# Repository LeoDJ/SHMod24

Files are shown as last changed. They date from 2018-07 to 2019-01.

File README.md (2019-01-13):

# SHMod24
(Smart Home Module NRF24)

WORK IN PROGRESS.

This PCB is a universal microcontroller board with many optionally placable components. It aims to be an universal base-board for many projects especially around home automation.

## Features
- Choice of ATMega328 (Arduino Pro Mini) or ESP8266 (ESP12-F) as the µC
- NRF24L01+ SMD with power filtering
- 6-30V input with buck converter
- Lithium battery support with charging and protection circuit
- 3.3V supply and logic
- Some MOSFET capable outputs
- RS485 Transceiver

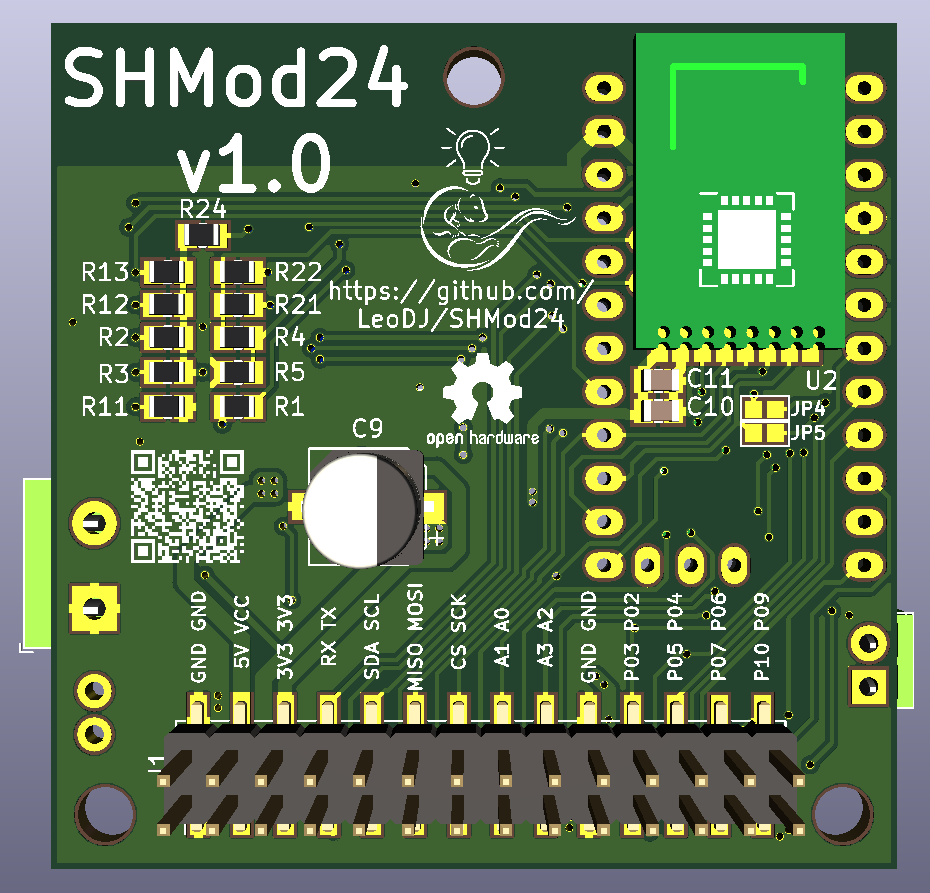
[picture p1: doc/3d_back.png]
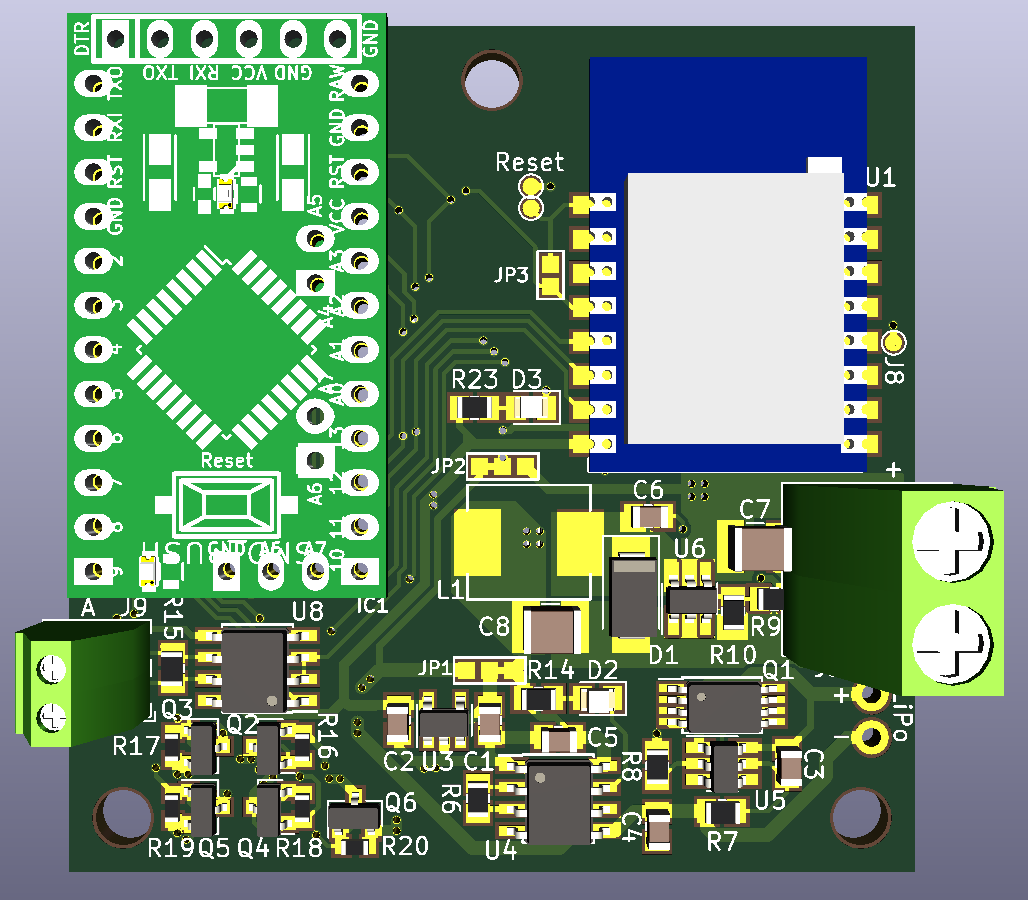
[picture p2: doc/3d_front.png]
|  |  |
| :--- | :--- |
| []() | []() |

## Pinout
The pinout of the 28 pin header is listed here:

| ESP8266 | Arduino | Function | Pin | Pin | Function  | Arduino | ESP8266 |
| :--- | :--- | :--- | :----- | :----- | :--- | :--- | :--- |
| | | GND | **1**  | **2**  | GND | | |
| | | 5V | **3**  | **4**  | VCC | | |
| | | 3.3V | **5**  | **6**  | 3.3V | | |
| RX | RX | RX | **7**  | **8**  | TX | TX | TX |
| GPIO4 | A4 | SDA | **9**  | **10** | SCL | A5 | GPIO5 |
| GPIO12 | 12 | MISO | **11** | **12** | MOSI | 11 | GPIO13 |
| GPIO15 | 8 | CS | **13** | **14** | SCK | 13 | GPIO14 |
| | A1 | | **15** | **16** | Analog in | A0 | ADC (0-3.3V) |
| | A3 | | **17** | **18** | | A2 | |
| | | GND | **19** | **20** | GND | | |
| GPIO2 | 3 | MOSFET | **21** | **22** | | 2 | GPIO0 |
| [GPIO13]<sup>* JP4</sup> | 5 | MOSFET | **23** | **24** | | 4 | |
| GPIO16 | 7 | NRF_CE | **25** | **26** | MOSFET | 6 | [GPIO12]<sup>* JP5</sup> |
| | 10 | MOSFET | **27** | **28** | MOSFET | 9 | |

*) GPIO can be connected to this pin by bridging the mentioned jumper

**ATTENTION:** When the MAX3485 is mounted the Arduino doesn't want to be programmed most of the time. So make sure to pull pin P3 to 3.3V.
## BOM
There are multiple different module groups that can be populated.

 **Information about what to watch out for for the different module groups will follow.**

 In the table is listed, which components to populate for a given module:

| Module | Reference | Part |
| :--- | :--- | :--- |
| **ESP8266** | U1 | ESP8266 12F |
| | R1, R2, R3, R11, R24 | 10k |
| ESP8266 ADC | R4 | 220k |
| | R5 | 100k |
| | | |
| **Arduino** | IC1 | Arduino Pro Mini |
| | | |
| **NRF radio** | U2 or U7 | NRF24L01+ SMD |
| | C11 | 100nF |
| | (C10) | 10µF |
| | | |
| **3.3V regulator** | U3 | AP2112K |
| | C1, C2 | 1µF |
| | | |
| **Buck regulator** | U6 | LMR14010A<br>or ACT4088 in deadbug style  |
| | R9 | LMR14010A: 56k<br>ACT4088: 47k |
| | R10 | 10k |
| | C6 | 100n |
| | C7 | LMR14010A: 2.2µF 50V<br>ACT4088: 10µF 50V |
| | C8 | 22µF |
| | L1 | LMR14010A: 22µH<br>ACT4088: 4.7µH |
| | D1 | Schottky 40V SMA |
| | (C9) | 100µF |
| | | |
| **LiPo charger** | U4 | TP4056 |
| | R6 | 2k2 |
| | C5 | 100nF |
| | R14 | 1k |
| | D2 | 0805 SMD LED (charging indicator) |
| | | |
| **LiPo protection** | U5 | DW01A |
| | Q1 | FS8205A |
| | R7 | 100 |
| | R8 | 1k |
| | C3 | 100n |
| | | |
| **I²C pullup resistors** | R12, R13 | 10k |
| | | |
| **RS485 Transceiver** | U8 | MAX3485 |

## Project installation
- Make sure to run `git clone` with `--recurse-submodules` to include the necessary libraries too.
- To use the 3D Models, set the following environment variables:
  - **ESPLIB** : `${KIPRJMOD}\lib_includes\kicad-ESP8266`
  - **MYSLOCAL** : `${KIPRJMOD}\lib_includes`
  - Note: Sometimes you need to manually replace `${KIPRJMOD}` with the absolute path to the project

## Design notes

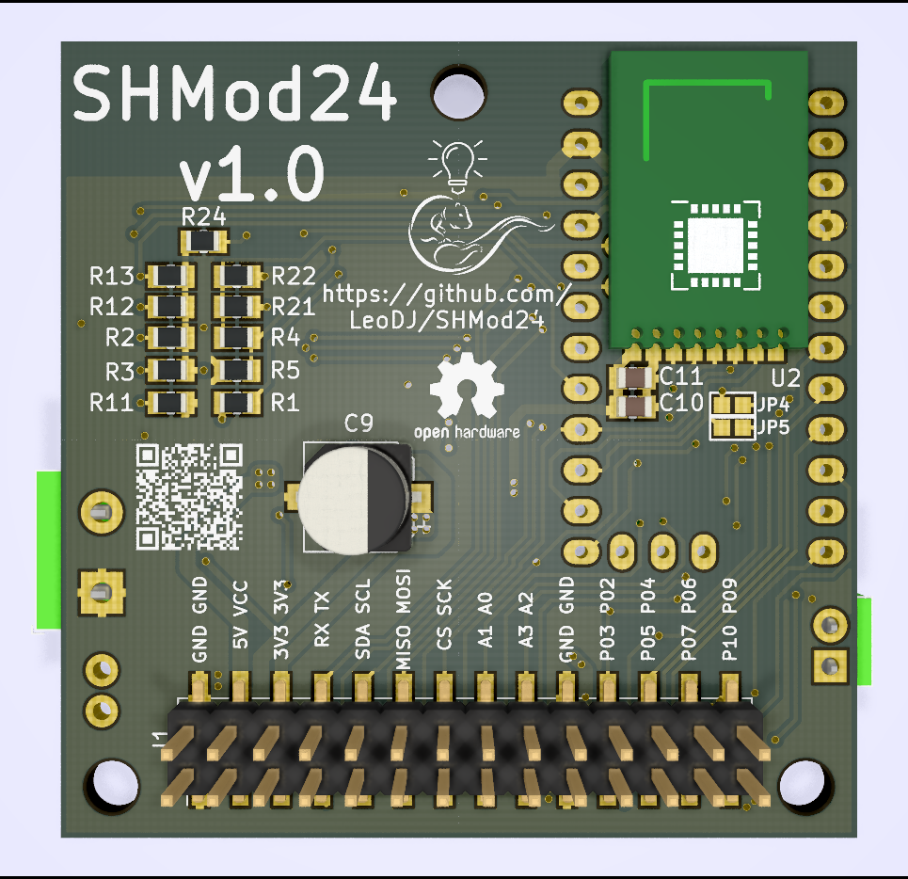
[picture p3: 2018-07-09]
doc/3d_rendered_back.png

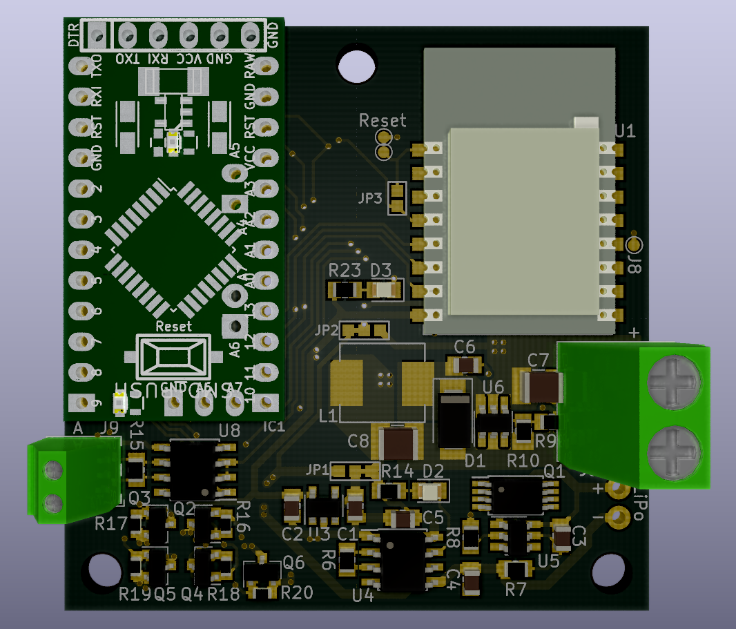
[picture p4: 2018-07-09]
doc/3d_rendered_front.png

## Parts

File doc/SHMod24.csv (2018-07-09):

Reference | Quantity | Value | Footprint | Datasheet
C1 C2 | 2 | 1µF | LeoDJ-kicad:C_0805_2012Metric
C11 C3 C5 | 3 | 100n | LeoDJ-kicad:C_0805_2012Metric
C10 C4 | 2 | 10µF | LeoDJ-kicad:C_0805_2012Metric
C6 | 1 | 100nF | LeoDJ-kicad:C_0805_2012Metric
C7 | 1 | 2.2µF 50V | Capacitor_SMD:C_1210_3225Metric
C8 | 1 | 22µF | Capacitor_SMD:C_1210_3225Metric
C9 | 1 | 100µF | Capacitor_SMD:CP_Elec_6.3x5.8
D1 | 1 | D_Schottky 40V | Diode_SMD:D_SMA
D2 D3 | 2 | LED | LED_SMD:LED_0805_2012Metric
IC1 | 1 | ArduinoProMini | mysensors_arduino:pro_mini
J1 | 1 | Conn_02x14_Odd_Even | Connector_PinHeader_2.54mm:PinHeader_2x14_P2.54mm_Vertical_SMD
J2 J3 | 2 | Conn_01x01 | Connector_Wire:SolderWirePad_1x01_Drill0.8mm
J4 | 1 | RESET | TestPoint:TestPoint_Pad_D1.0mm
J5 | 1 | 12V | TerminalBlock_Phoenix:TerminalBlock_Phoenix_MKDS-1,5-2_1x02_P5.00mm_Horizontal
J6 J8 | 2 | GND | TestPoint:TestPoint_Pad_D1.0mm
J9 | 1 | Screw_Terminal_01x02 | LeoDJ-kicad:TerminalBlock_Phoenix_MPT-0,5-2-2.54_1x02_P2.54mm_Horizontal_fixed
JP1 | 1 | Source Select | LeoDJ-kicad:SOLDER-JUMPER_2-WAY
JP2 | 1 | VoltSense | LeoDJ-kicad:SOLDER-JUMPER_2-WAY
JP3 | 1 | Jumper_DeepSleep | LeoDJ-kicad:SOLDER-JUMPER_1-WAY
JP4 JP5 | 2 | ESP_MOSFET | LeoDJ-kicad:SOLDER-JUMPER_1-WAY
L1 | 1 | 22µH | LeoDJ-kicad:L_0630
LOGO1 | 1 | Logo_Open_Hardware_Small | Symbol:OSHW-Logo2_7.3x6mm_SilkScreen
MK1 MK2 MK3 | 3 | Mounting_Hole | MountingHole:MountingHole_3.2mm_M3
Q1 | 1 | FS8205A | Package_SO:TSSOP-8_4.4x3mm_P0.65mm
Q2 Q3 Q4 Q5 Q6 | 5 | AO3400A | Package_TO_SOT_SMD:SOT-23 | http://www.aosmd.com/pdfs/datasheet/AO3400A.pdf
R1 R10 R11 R12 R13 R2 R24 R3 | 8 | 10k | LeoDJ-kicad:R_0805_2012Metric
R15 | 1 | 120 | LeoDJ-kicad:R_0805_2012Metric
R16 R17 R18 R19 R20 | 5 | 10k | Resistor_SMD:R_0603_1608Metric
R21 | 1 | 47k/220k | LeoDJ-kicad:R_0805_2012Metric
R22 | 1 | 22k | LeoDJ-kicad:R_0805_2012Metric
R4 | 1 | 220k | LeoDJ-kicad:R_0805_2012Metric
R5 | 1 | 100k | LeoDJ-kicad:R_0805_2012Metric
R6 | 1 | 2k2 | LeoDJ-kicad:R_0805_2012Metric
R7 | 1 | 100 | LeoDJ-kicad:R_0805_2012Metric
R14 R23 R8 | 3 | 1k | LeoDJ-kicad:R_0805_2012Metric
R9 | 1 | 56k | LeoDJ-kicad:R_0805_2012Metric
SYM1 | 1 | SYM_Arrow_Tiny | leodj-kicad:Otter_Lightbulb_smaller
SYM2 | 1 | SYM_Arrow_Tiny | leodj-kicad:QR_Code_SHMod24
U1 | 1 | ESP-12 | ESP8266:ESP-12E_SMD
U2 U7 | 2 | NRF24L01 | mysensors_radios:NRF24L01-SMD
U3 | 1 | AP2112K-3.3 | Package_TO_SOT_SMD:SOT-23-5
U4 | 1 | TP4056 | Package_SO:SOIC-8_3.9x4.9mm_P1.27mm
U5 | 1 | DW01A | Package_TO_SOT_SMD:SOT-23-6_Handsoldering
U6 | 1 | LMR14010A | Package_TO_SOT_SMD:SOT-23-6_Handsoldering
U8 | 1 | MAX3485 | Package_SO:SOIC-8_3.9x4.9mm_P1.27mm | https://datasheets.maximintegrated.com/en/ds/MAX3483-MAX3491.pdf

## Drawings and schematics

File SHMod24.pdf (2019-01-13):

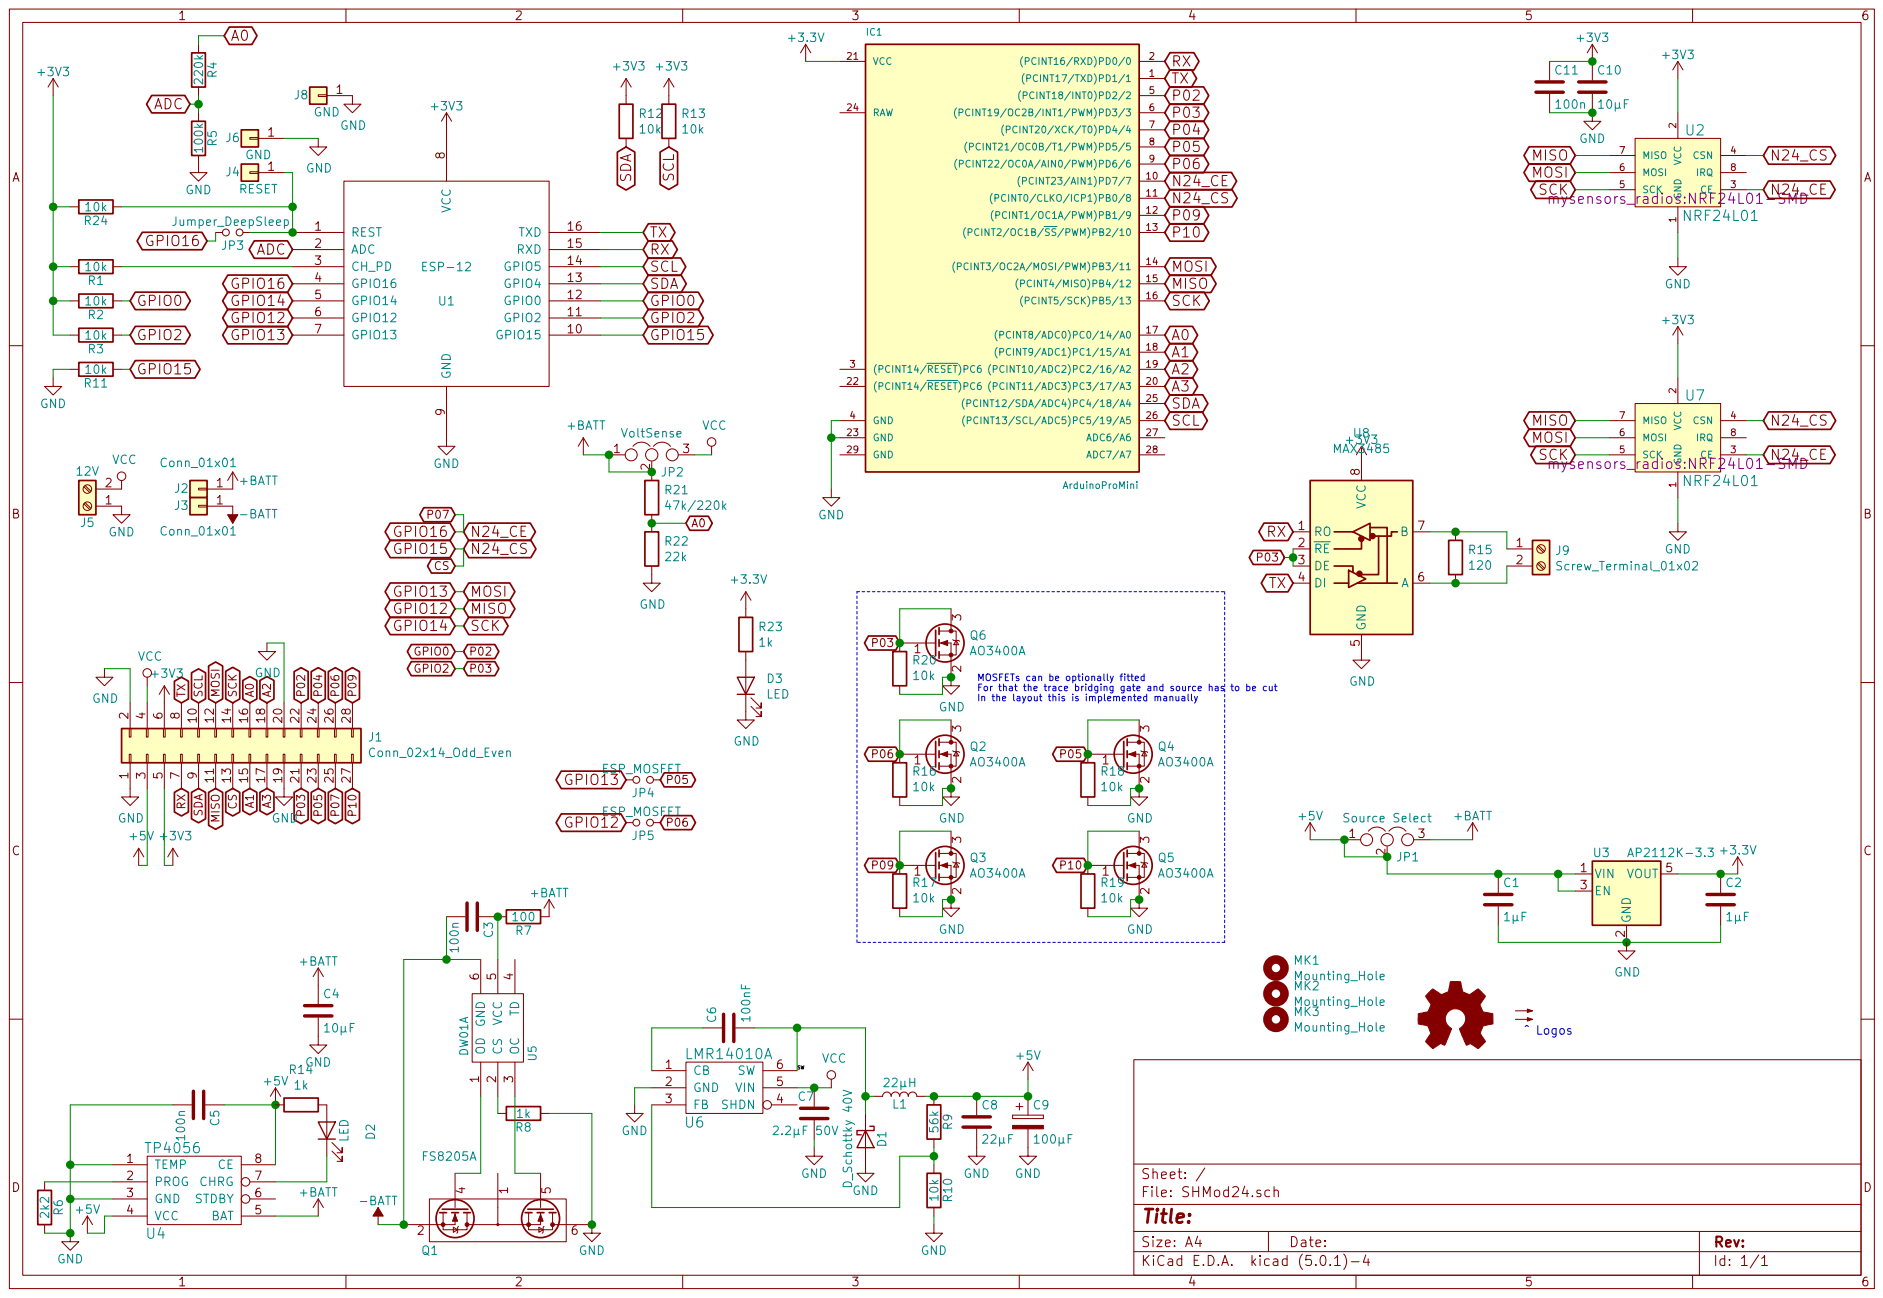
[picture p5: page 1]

2 CE 3 CSN 4 SCK 5 MOSI 6 MISO 7

2 3 Q5AO3400A P09 P10 GND GND GND GND

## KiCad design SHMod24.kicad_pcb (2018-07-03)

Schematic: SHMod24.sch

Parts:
C1, C2: 1µF; C_0805_2012Metric
C3, C5, C11: 100n; C_0805_2012Metric
C4, C10: 10µF; C_0805_2012Metric
C6: 100nF; C_0805_2012Metric
C7: 2.2µF 50V; C_1210_3225Metric
C8: 22µF; C_1210_3225Metric
C9: 100µF; CP_Elec_6.3x5.8
D1: D_Schottky 40V; D_SMA
D2, D3: LED; LED_0805_2012Metric
IC1: ArduinoProMini; pro_mini
J1: Conn_02x14_Odd_Even; PinHeader_2x14_P2.54mm_Vertical_SMD
J2, J3: Conn_01x01; SolderWirePad_1x01_Drill0.8mm
J4: RESET; TestPoint_Pad_D1.0mm
J5: 12V; TerminalBlock_Phoenix_MKDS-1,5-2_1x02_P5.00mm_Horizontal
J6, J8: GND; TestPoint_Pad_D1.0mm
J9: Screw_Terminal_01x02; TerminalBlock_Phoenix_MPT-0,5-2-2.54_1x02_P2.54mm_Horizonta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
JP1: Source Select; SOLDER-JUMPER_2-WAY
JP2: VoltSense; SOLDER-JUMPER_2-WAY
JP3: Jumper_DeepSleep; SOLDER-JUMPER_1-WAY
JP4, JP5: ESP_MOSFET; SOLDER-JUMPER_1-WAY
L1: 22µH; L_0630
LOGO1: Logo_Open_Hardware_Small; OSHW-Logo2_7.3x6mm_SilkScreen
MK1, MK2, MK3: Mounting_Hole; MountingHole_3.2mm_M3
Q1: FS8205A; TSSOP-8_4.4x3mm_P0.65mm
Q2, Q3, Q4, Q5, Q6: AO3400A; SOT-23
R1, R2, R3, R10, R11, R12, R13, R24: 10k; R_0805_2012Metric
R4: 220k; R_0805_2012Metric
R5: 100k; R_0805_2012Metric
R6: 2k2; R_0805_2012Metric
R7: 100; R_0805_2012Metric
R8, R14, R23: 1k; R_0805_2012Metric
R9: 56k; R_0805_2012Metric
R15: 120; R_0805_2012Metric
R16, R17, R18, R19, R20: 10k; R_0603_1608Metric
R21: 47k/220k; R_0805_2012Metric
R22: 22k; R_0805_2012Metric
SYM1: SYM_Arrow_Tiny; Otter_Lightbulb_smaller
SYM2: SYM_Arrow_Tiny; QR_Code_SHMod24
U1: ESP-12; ESP-12E_SMD
U2, U7: NRF24L01; NRF24L01-SMD
U3: AP2112K-3.3; SOT-23-5
U4: TP4056; SOIC-8_3.9x4.9mm_P1.27mm
U5: DW01A; SOT-23-6_Handsoldering
U6: LMR14010A; SOT-23-6_Handsoldering
U8: MAX3485; SOIC-8_3.9x4.9mm_P1.27mm

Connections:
+3V3: C2.1, C10.1, C11.1, IC1.21, J1.5, J1.6, R1.2, R2.2, R3.2, R12.1, R13.1, R23.1, R24.2, U1.8, U2.2, U3.5, U7.2, U8.8 (VCC)
+5V: C1.1, C5.1, C8.1, C9.1, J1.3, JP1.1, JP1.2, L1.2, R9.1, R14.1, U3.1, U3.3, U4.4, U4.8
+BATT: C4.1, J2.1, JP1.3, JP2.1, JP2.2, R7.1, R21.1, U4.5
-BATT: C3.2, J3.1, Q1.2, U5.6
/SW: C6.2, D1.1, L1.1, U6.6
A0: IC1.17, J1.16, R4.1, R21.2, R22.1
A1: IC1.18, J1.15
A2: IC1.19, J1.18
A3: IC1.20, J1.17
ADC: R4.2, R5.1, U1.2
CS: IC1.11, J1.13, R11.1, U1.10, U2.4, U7.4
GND: C1.2, C2.2, C4.2, C5.2, C7.2, C8.2, C9.2, C10.2, C11.2, D1.2, D3.1, IC1.4, IC1.23, J1.1, J1.2, J1.19, J1.20, J5.1, J6.1, J8.1, Q1.6, Q2.2, Q3.2, Q4.2, Q5.2, Q6.2, R5.2, R6.2, R8.1, R10.2, R11.2, R16.1, R17.1, R18.1, R19.1, R20.1, R22.2, U1.9, U2.1, U3.2, U4.1, U4.3, U6.2, U7.1, U8.5 (GND)
GPIO0: IC1.5, J1.22, R2.1, U1.12
GPIO2: IC1.6, J1.21, Q6.1, Q6.3, R3.1, R20.2, U1.11, U8.2 (~RE), U8.3 (DE)
GPIO12: IC1.15, J1.11, JP5.2, U1.6, U2.7, U7.7
GPIO13: IC1.14, J1.12, JP4.2, U1.7, U2.6, U7.6
GPIO14: IC1.16, J1.14, U1.5, U2.5, U7.5
GPIO16: IC1.10, J1.25, JP3.2, U1.4, U2.3, U7.3
unnamed: C3.1, R7.2, U5.5
unnamed: C6.1, U6.1
unnamed: D2.1, U4.7
unnamed: D2.2, R14.2
unnamed: D3.2, R23.2
unnamed: J4.1, JP3.1, R24.1, U1.1
unnamed: J9.1, R15.1, U8.7 (B)
unnamed: J9.2, R15.2, U8.6 (A)
unnamed: Q1.4, U5.1
unnamed: Q1.5, U5.3
unnamed: R1.1, U1.3
unnamed: R6.1, U4.2
unnamed: R8.2, U5.2
unnamed: R9.2, R10.1, U6.3
P04: IC1.7, J1.24
P05: IC1.8, J1.23, JP4.1, Q4.1, Q4.3, R18.2
P06: IC1.9, J1.26, JP5.1, Q2.1, Q2.3, R16.2
P09: IC1.12, J1.28, Q3.1, Q3.3, R17.2
P10: IC1.13, J1.27, Q5.1, Q5.3, R19.2
RX: IC1.2, J1.7, U1.15, U8.1 (RO)
SCL: IC1.26, J1.10, R13.2, U1.14
SDA: IC1.25, J1.9, R12.2, U1.13
TX: IC1.1, J1.8, U1.16, U8.4 (DI)
VCC: C7.1, J1.4, J5.2, JP2.3, U6.5

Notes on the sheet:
MOSFETs can be optionally fitted For that the trace bridging gate and source has to be cut In the layout this is implemented manually
^ Logos

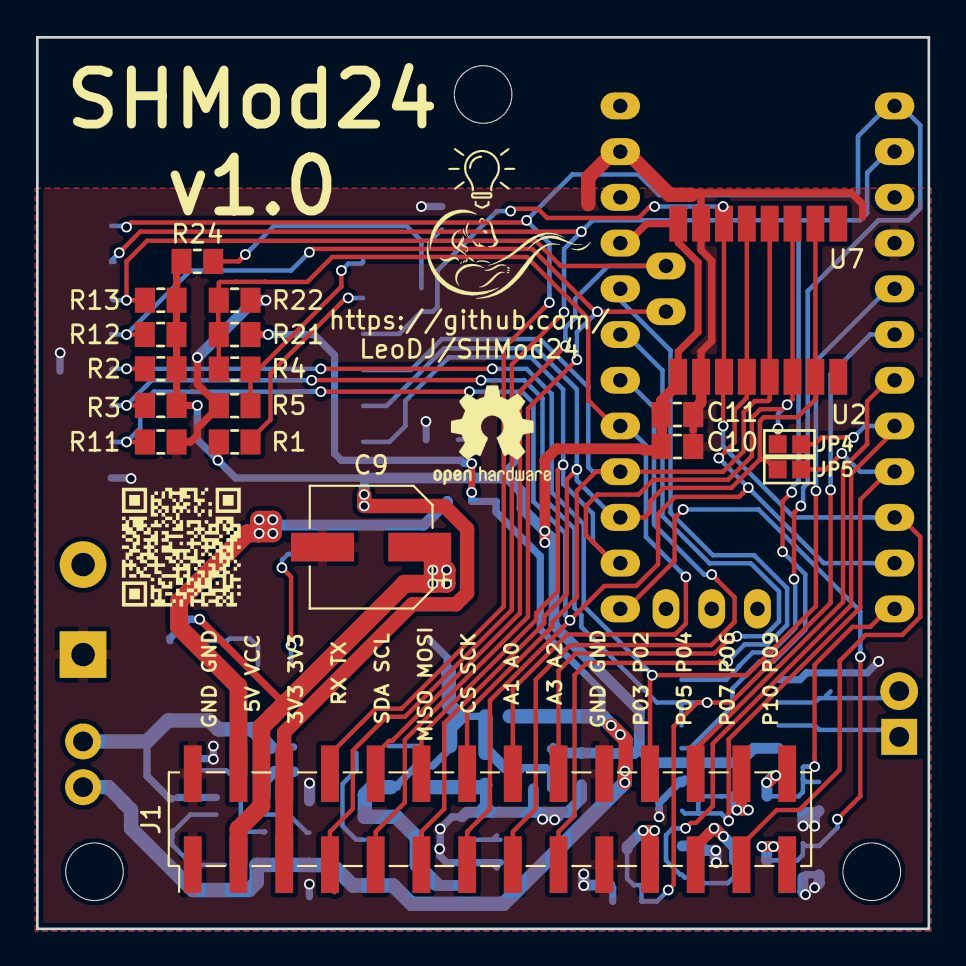
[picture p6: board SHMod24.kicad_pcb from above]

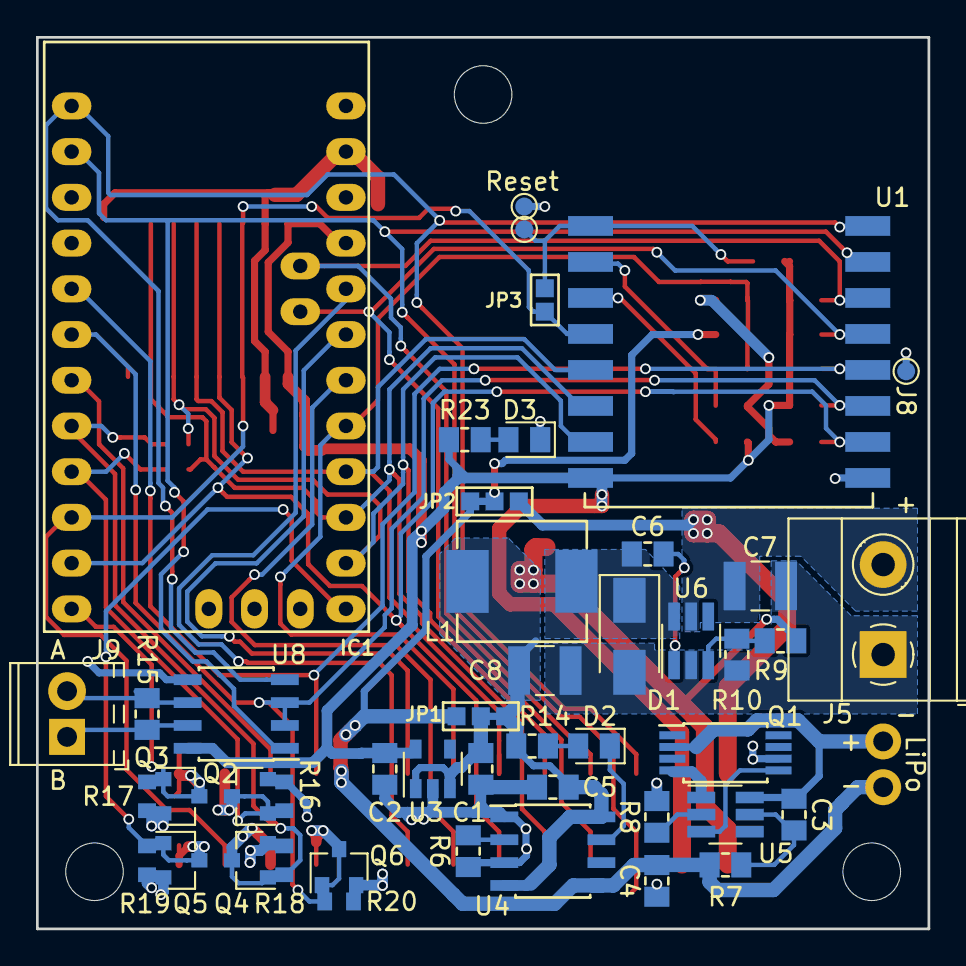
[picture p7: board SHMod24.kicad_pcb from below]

Board: 2 copper layers, 49.5 x 49.5 mm, 73 parts (46 on the bottom side), 42 nets.

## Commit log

2018-05-04 include footprints
    [SHMod24.sch]
2018-05-04 NRF ESP Jumper
    [SHMod24.kicad_pcb, SHMod24.sch]
2018-05-20 migrate to KiCad5 && further layouting
    [SHMod24.kicad_pcb, SHMod24.sch]
2018-05-23 more layouting
    [SHMod24.kicad_pcb, SHMod24.sch]
2018-05-23 even more layouting
    [SHMod24.kicad_pcb, SHMod24.sch]
2018-05-23 layouting of the current schematic complete
    [SHMod24.kicad_pcb, SHMod24.sch]
2018-05-23 move component references
    [SHMod24.kicad_pcb]
2018-05-27 add holes
    [SHMod24.kicad_pcb]
2018-05-29 minor changes
    [SHMod24.kicad_pcb, SHMod24.sch]
2018-06-07 add RS485 and MOSFETs
    [SHMod24.kicad_pcb, SHMod24.sch]
2018-06-07 add MOSFET pulldowns
    [SHMod24.kicad_pcb, SHMod24.sch]
2018-06-07 add fifth MOSFET
    [SHMod24.kicad_pcb, SHMod24.sch]
2018-06-07 add high voltage sense input
    [SHMod24.kicad_pcb, SHMod24.sch]
2018-06-10 begin switching regulator improvement
    [SHMod24.kicad_pcb, SHMod24.sch]
2018-06-16 fix switching regulator layout
    [SHMod24.kicad_pcb]
2018-06-17 improve switching regulator capacitor placement
    [SHMod24.kicad_pcb]
2018-06-17 add power LED && place references better
    [SHMod24.kicad_pcb, SHMod24.sch]
2018-06-18 fix LDO no GND && minor trace improvements
    [SHMod24.kicad_pcb, SHMod24.sch]
2018-06-24 more layout improvements
    [SHMod24.kicad_pcb, SHMod24.sch]
2018-06-24 more improvements
    [SHMod24.kicad_pcb, SHMod24.sch]
2018-06-30 improve routing for 485 transceiver
    [SHMod24.kicad_pcb]
2018-07-03 final improvements: better track layout, silk screen symbols
    [SHMod24.kicad_pcb, SHMod24.sch]
2018-07-03 add RS485 connector markings
    [SHMod24.kicad_pcb, SHMod24.sch]
2018-07-03 final touches & gerber files
    [SHMod24-B.Cu.gbr, SHMod24-B.Mask.gbr, SHMod24-B.SilkS.gbr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]
2018-07-09 add rendered pictures
    [SHMod24.csv]
2019-01-13 update README && add schematic pdf
